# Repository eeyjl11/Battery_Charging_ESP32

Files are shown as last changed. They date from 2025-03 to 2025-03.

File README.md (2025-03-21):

# Battery_Charging_ESP32
 ESP32 S3 with integrated li-ion battery charging.
 
 ## MCP73831T-5ACI_OT
 For charging battery.
 
 ## DW01A and FS8205
 Handles battery protection.
 
 ## AMS1117-3.3
 3.3V Voltage regulator for ESP32.
 
 ## TO DO:
 - Bill of materials
 - Position file for JLCPCB pick and place
 - Generate gerber and drill files

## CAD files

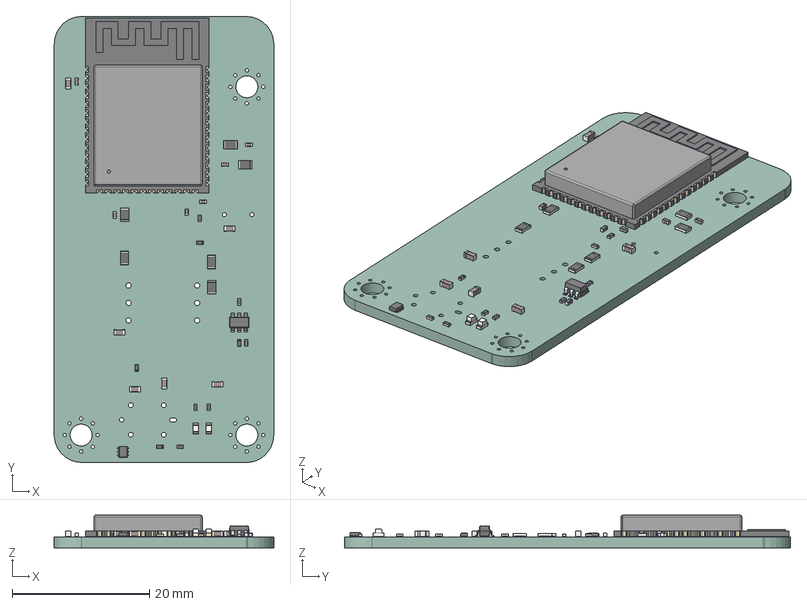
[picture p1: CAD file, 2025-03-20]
battery_charging_esp32.step
32.0 x 65.0 x 4.75 mm
R_0402_1005Metric x 9
R_0805_2012Metric x 6
SOT_23_6
C_0402_1005Metric x 7
C_0603_1608Metric x 6
SOT_666
ESP32-S3-WROOM-1
LED_0603_1608Metric x 2
esp32_battery_pressure_sensor_PCB

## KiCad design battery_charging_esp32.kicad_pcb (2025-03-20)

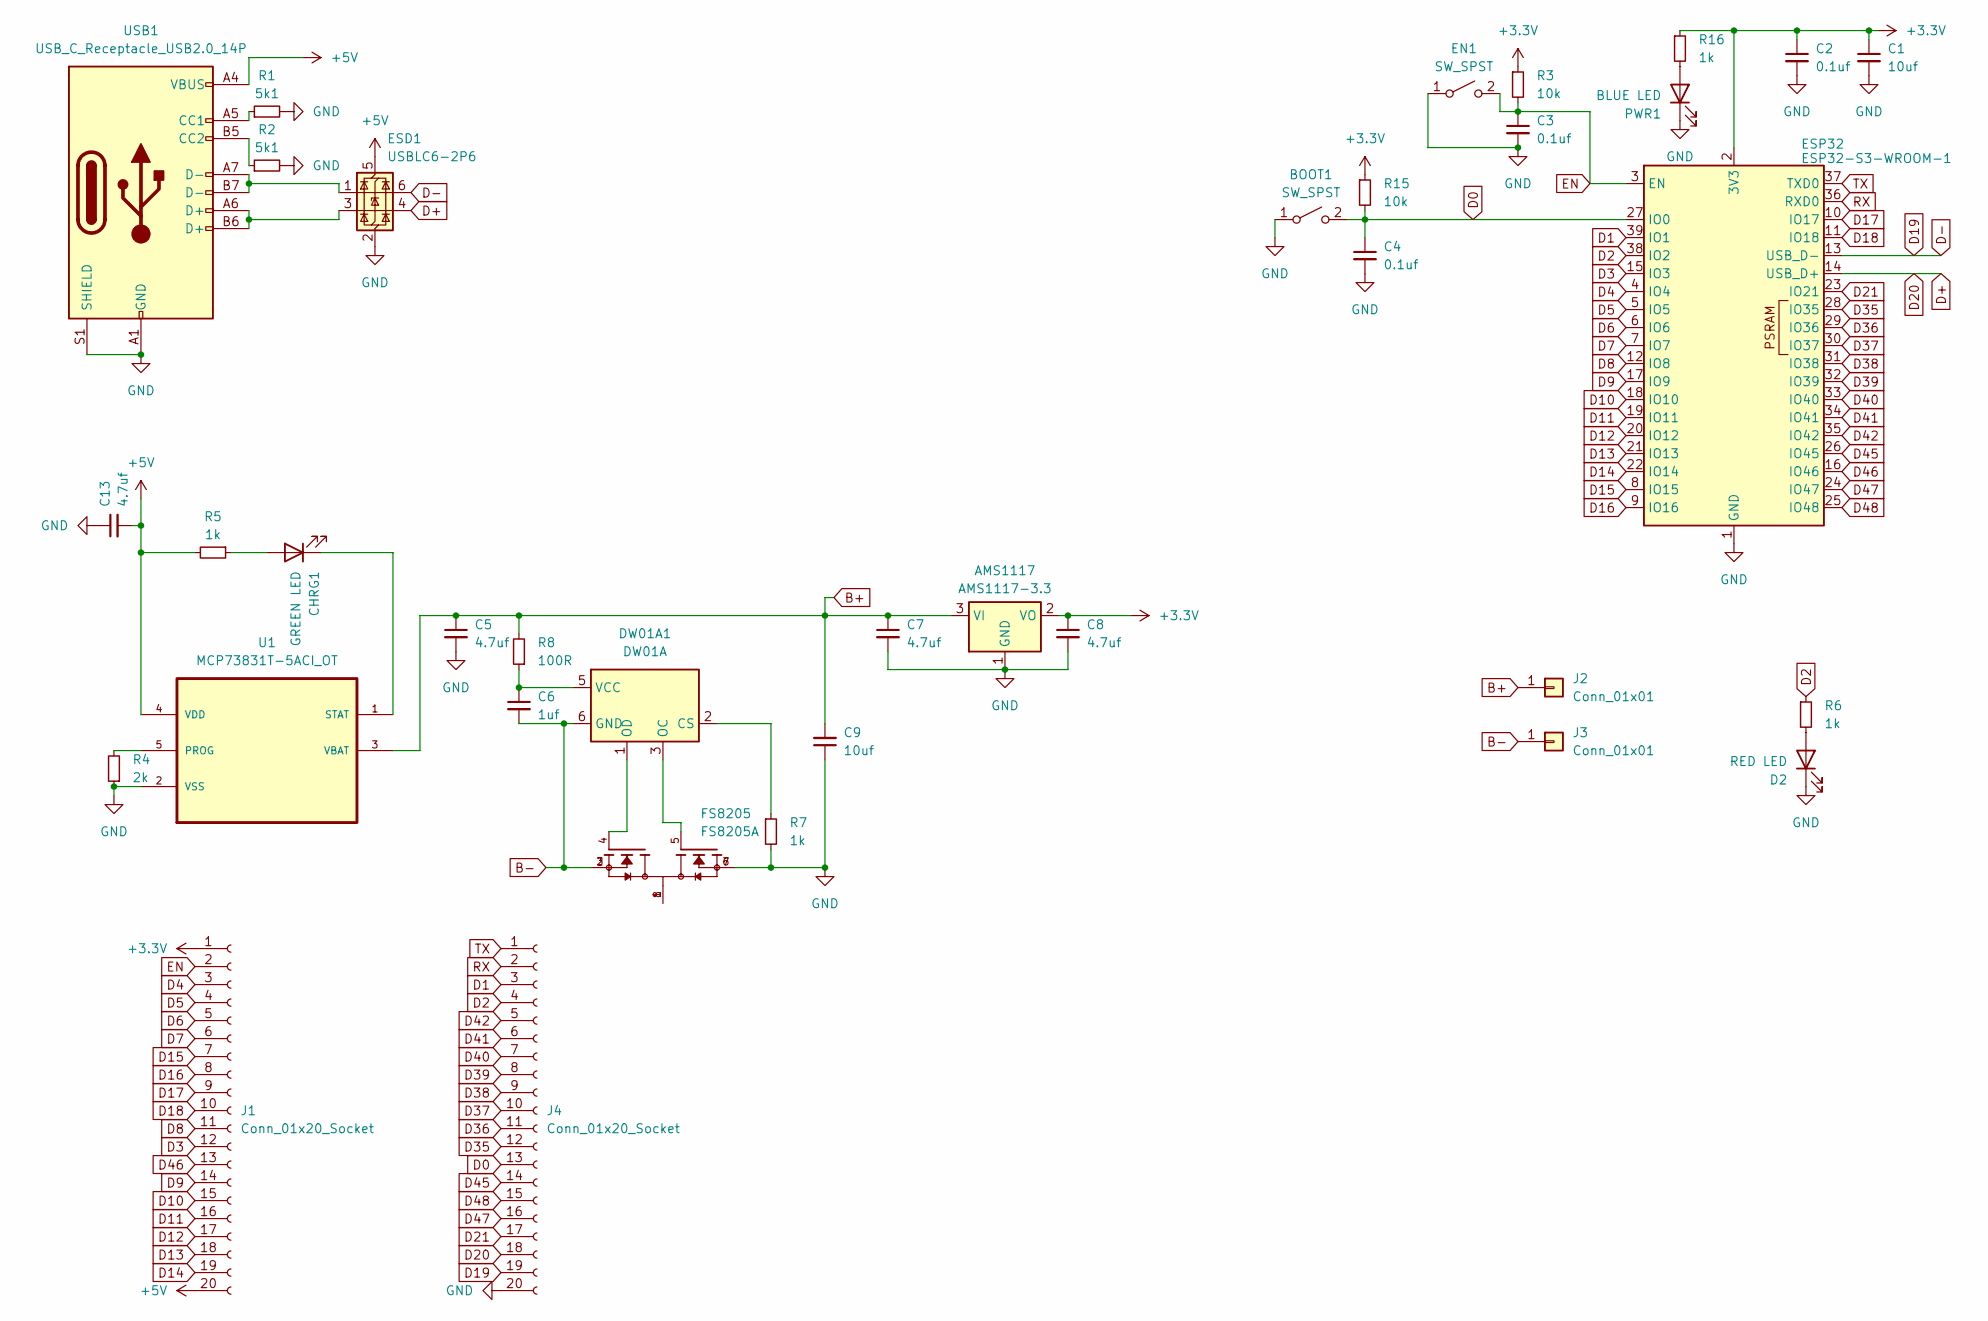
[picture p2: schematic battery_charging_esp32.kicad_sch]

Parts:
AMS1117: AMS1117-3.3; SOT-223-3_TabPin2
BOOT1: SW_SPST; SW_Push_SPST_NO_Alps_SKRK
C1, C9: 10uf; C_0603_1608Metric
C2, C3, C4: 0.1uf; C_0402_1005Metric
C5, C7, C8, C13: 4.7uf; C_0603_1608Metric
C6: 1uf; C_0402_1005Metric
CHRG1: GREEN LED; LED_0603_1608Metric
D2: RED LED; LED_0603_1608Metric
DW01A1: DW01A; SOT-23-6
EN1: SW_SPST; SW_Push_SPST_NO_Alps_SKRK
ESD1: USBLC6-2P6; SOT-666
ESP32: ESP32-S3-WROOM-1
FS8205: FS8205A; SOP65P640X120-8N; PARTREV 1.7
J1, J4: Conn_01x20_Socket; PinSocket_1x20_P2.54mm_Vertical
J2, J3: Conn_01x01; SolderWire-0.1sqmm_1x01_D0.4mm_OD1mm
PWR1: BLUE LED; LED_0603_1608Metric
R1, R2: 5k1; R_0402_1005Metric
R3, R15: 10k; R_0805_2012Metric
R4: 2k; R_0402_1005Metric
R5, R6, R7, R16: 1k; R_0402_1005Metric
R8: 100R; R_0402_1005Metric
U1: MCP73831T-5ACI_OT; SOT95P280X145-5N; MPN MCP73831T-5ACI/OT
USB1: USB_C_Receptacle_USB2.0_14P; USB_C_Receptacle_GCT_USB4105-xx-A_16P_TopMnt_Horizontal

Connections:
+3.3V: AMS1117.2 (VO), C1.1, C2.1, C8.1, ESP32.2 (3V3), J1.1, R3.1, R15.1, R16.1
+5V: C13.2, ESD1.5 (VBUS), J1.20, R5.2, U1.4 (VDD), USB1.A4 (VBUS), USB1.A9 (VBUS), USB1.B4 (VBUS), USB1.B9 (VBUS)
B+: AMS1117.3 (VI), C5.1, C7.1, C9.2, J2.1, R8.2, U1.3 (VBAT)
B-: C6.2, DW01A1.6 (GND), FS8205.2, FS8205.3, J3.1
D0: BOOT1.2 (B), C4.1, ESP32.27 (IO0), J4.13, R15.2
D1: ESP32.39 (IO1), J4.3
D2: ESP32.38 (IO2), J4.4, R6.1
D3: ESP32.15 (IO3), J1.12
D4: ESP32.4 (IO4), J1.3
D5: ESP32.5 (IO5), J1.4
D6: ESP32.6 (IO6), J1.5
D7: ESP32.7 (IO7), J1.6
D8: ESP32.12 (IO8), J1.11
D9: ESP32.17 (IO9), J1.14
D10: ESP32.18 (IO10), J1.15
D11: ESP32.19 (IO11), J1.16
D12: ESP32.20 (IO12), J1.17
D13: ESP32.21 (IO13), J1.18
D14: ESP32.22 (IO14), J1.19
D15: ESP32.8 (IO15), J1.7
D16: ESP32.9 (IO16), J1.8
D17: ESP32.10 (IO17), J1.9
D18: ESP32.11 (IO18), J1.10
D21: ESP32.23 (IO21), J4.17
D35: ESP32.28 (IO35), J4.12
D36: ESP32.29 (IO36), J4.11
D37: ESP32.30 (IO37), J4.10
D38: ESP32.31 (IO38), J4.9
D39: ESP32.32 (IO39), J4.8
D40: ESP32.33 (IO40), J4.7
D41: ESP32.34 (IO41), J4.6
D42: ESP32.35 (IO42), J4.5
D45: ESP32.26 (IO45), J4.14
D46: ESP32.16 (IO46), J1.13
D47: ESP32.24 (IO47), J4.16
D48: ESP32.25 (IO48), J4.15
D+: ESD1.4 (I/O2), ESP32.14 (USB_D+), J4.18
D-: ESD1.6 (I/O1), ESP32.13 (USB_D-), J4.19
EN: C3.1, EN1.2 (B), ESP32.3 (EN), J1.2, R3.2
GND: AMS1117.1 (GND), BOOT1.1 (A), C1.2, C2.2, C3.2, C4.2, C5.2, C7.2, C8.2, C9.1, C13.1, D2.1 (K), EN1.1 (A), ESD1.2 (GND), ESP32.1 (GND), ESP32.40 (GND), ESP32.41 (GND), FS8205.6, FS8205.7, J4.20, PWR1.1 (K), R1.2, R2.2, R4.1, R7.2, U1.2 (VSS), USB1.A1 (GND), USB1.A12 (GND), USB1.B1 (GND), USB1.B12 (GND), USB1.S1 (SHIELD)
unnamed: CHRG1.2 (A), R5.1
unnamed: CHRG1.1 (K), U1.1 (STAT)
unnamed: D2.2 (A), R6.2
unnamed: DW01A1.2 (CS), R7.1
unnamed: DW01A1.3 (OC), FS8205.5
unnamed: DW01A1.1 (OD), FS8205.4
unnamed: C6.1, DW01A1.5 (VCC), R8.1
unnamed: ESD1.1 (I/O1), USB1.A7 (D-), USB1.B7 (D-)
unnamed: ESD1.3 (I/O2), USB1.A6 (D+), USB1.B6 (D+)
unnamed: FS8205.1, FS8205.8
unnamed: PWR1.2 (A), R16.2
unnamed: R4.2, U1.5 (PROG)
unnamed: R1.1, USB1.A5 (CC1)
unnamed: R2.1, USB1.B5 (CC2)
RX: ESP32.36 (RXD0), J4.2
TX: ESP32.37 (TXD0), J4.1

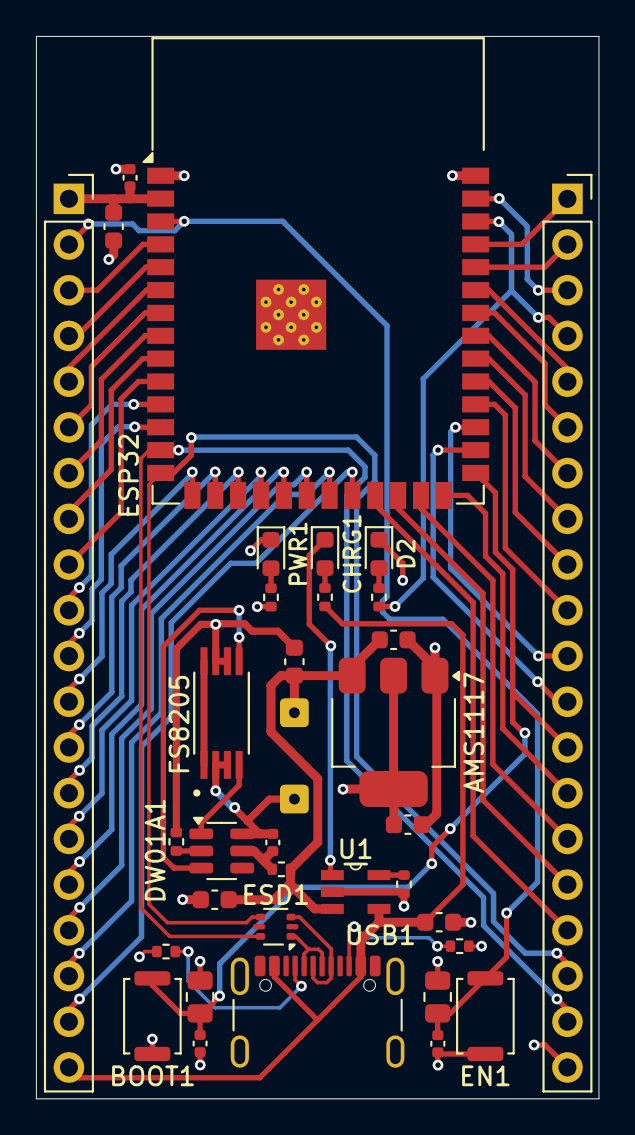
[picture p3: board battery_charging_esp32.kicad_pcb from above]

Board: 4 copper layers, 31.2 x 59.0 mm, 36 parts (0 on the bottom side), 56 nets.
